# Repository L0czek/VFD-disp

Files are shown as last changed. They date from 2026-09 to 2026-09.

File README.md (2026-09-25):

# IVLM3 driver board

This project was created to drive the old IVLM3-5/7 VFD displays. These tubes are tricolor 5×7 matrices that allow displaying arbitrary shapes, provided you stand far enough for the subpixels to blend. The board consists of several sections and is controlled via an ESP32-C6 module, which uses the HV5812 as the anode and grid driver. These tubes require anode voltages of up to 50V in pulse mode with 3V heating, so the board features a boost and buck converter to achieve these voltages.

**Assembled board.**  
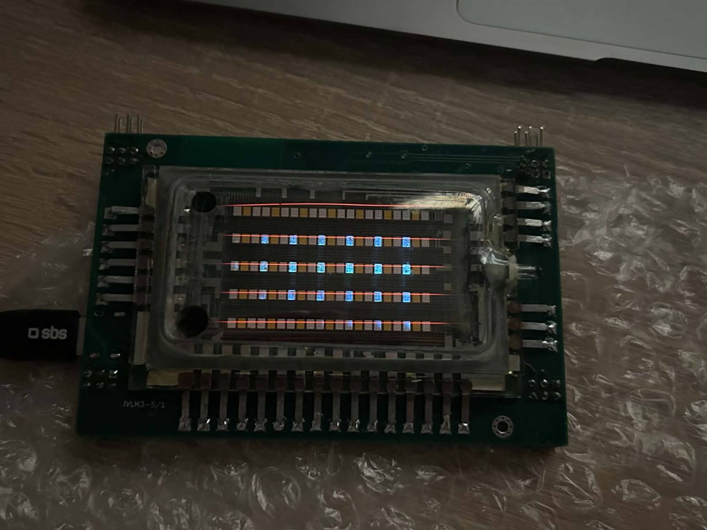
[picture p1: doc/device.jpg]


**All pixels lit at 10V anode.**  
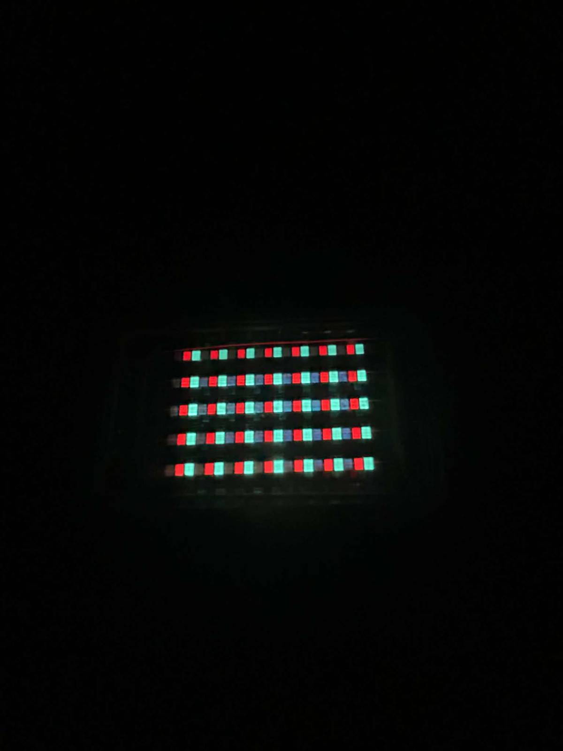
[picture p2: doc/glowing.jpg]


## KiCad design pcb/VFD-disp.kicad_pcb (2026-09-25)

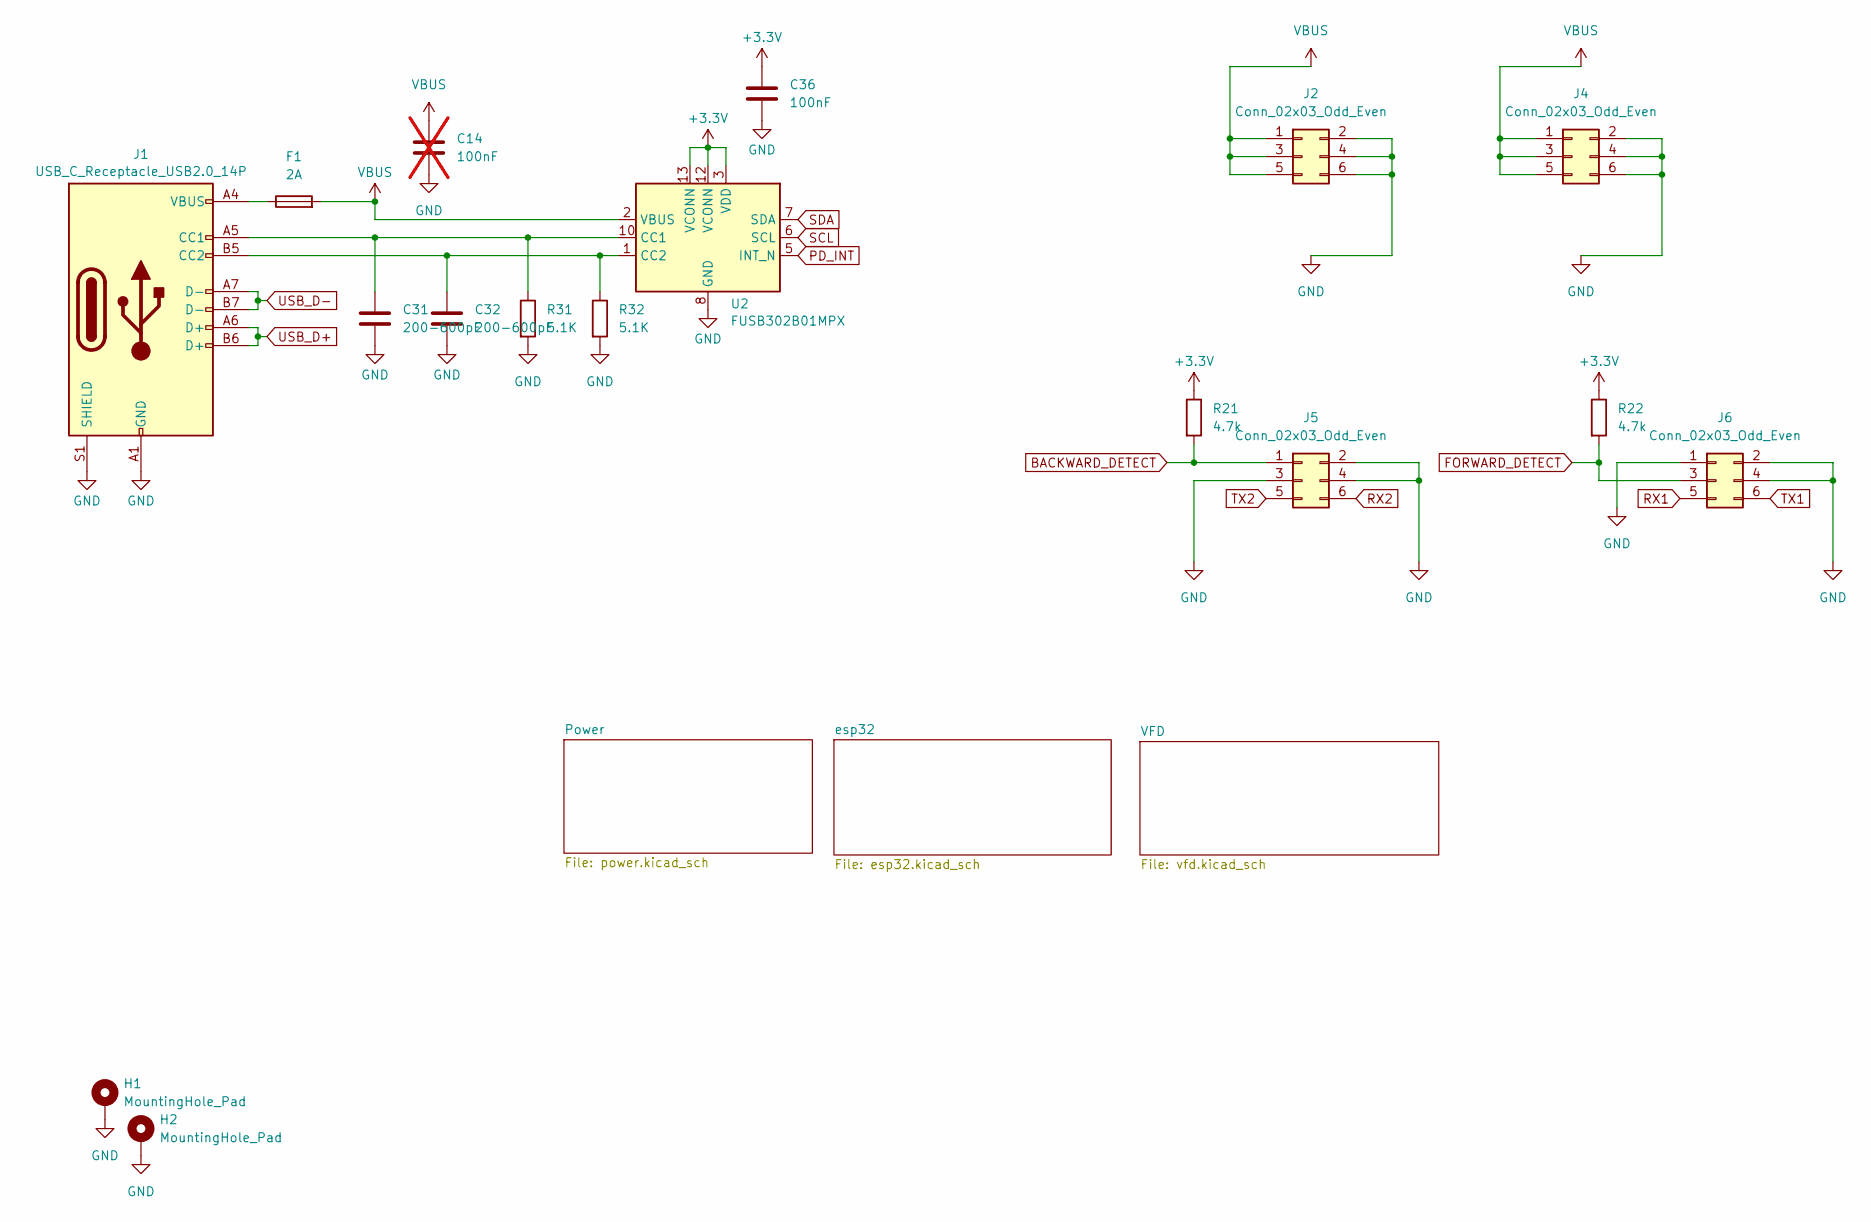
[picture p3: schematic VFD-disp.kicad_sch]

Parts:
C14: 100nF; C_2220_5750Metric; not fitted
C31, C32: 200-600pF; C_0805_2012Metric
C36: 100nF; C_0805_2012Metric; LCSC C7419429
F1: 2A; Fuse_0805_2012Metric
H1, H2: MountingHole_Pad; MountingHole_2.2mm_M2_Pad_Via
J1: USB_C_Receptacle_USB2.0_14P; USB_C_Receptacle_G-Switch_GT-USB-7010ASV
J2, J5: Conn_02x03_Odd_Even; PinSocket_2x03_P2.54mm_Horizontal
J4, J6: Conn_02x03_Odd_Even; PinHeader_2x03_P2.54mm_Horizontal
R21, R22: 4.7k; R_0805_2012Metric; LCSC C7468408
R31, R32: 5.1K; R_0805_2012Metric
U2: FUSB302B01MPX; WQFN-14-1EP_2.5x2.5mm_P0.5mm_EP1.45x1.45mm

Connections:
+3.3V: C36.1, R21.1, R22.1, U2.3 (VDD), U2.4 (VDD), U2.12 (VCONN), U2.13 (VCONN); also elsewhere on the board
BACKWARD_DETECT: J5.1, R21.2; also elsewhere on the board
FORWARD_DETECT: J6.3, R22.2; also elsewhere on the board
GND: C14.2, C31.2, C32.2, C36.2, H1.1 (1_1), H2.1 (1_1), J1.A1 (GND), J1.A12 (GND), J1.B1 (GND), J1.B12 (GND), J1.S1 (SHIELD), J2.2, J2.4, J2.6, J4.2, J4.4, J4.6, J5.2, J5.3, J5.4, J6.1, J6.2, J6.4, R31.2, R32.2, U2.8 (GND), U2.9 (GND), U2.15 (GND); also elsewhere on the board
unnamed: F1.1, J1.A4 (VBUS), J1.A9 (VBUS), J1.B4 (VBUS), J1.B9 (VBUS)
unnamed: C31.1, J1.A5 (CC1), R31.1, U2.10 (CC1), U2.11 (CC1)
unnamed: C32.1, J1.B5 (CC2), R32.1, U2.1 (CC2), U2.14 (CC2)
PD_INT: U2.5 (INT_N); also elsewhere on the board
RX1: J6.5; also elsewhere on the board
RX2: J5.6; also elsewhere on the board
SCL: U2.6 (SCL); also elsewhere on the board
SDA: U2.7 (SDA); also elsewhere on the board
TX1: J6.6; also elsewhere on the board
TX2: J5.5; also elsewhere on the board
USB_D+: J1.A6 (D+), J1.B6 (D+); also elsewhere on the board
USB_D-: J1.A7 (D-), J1.B7 (D-); also elsewhere on the board
VBUS: C14.1, F1.2, J2.1, J2.3, J2.5, J4.1, J4.3, J4.5, U2.2 (VBUS); also elsewhere on the board

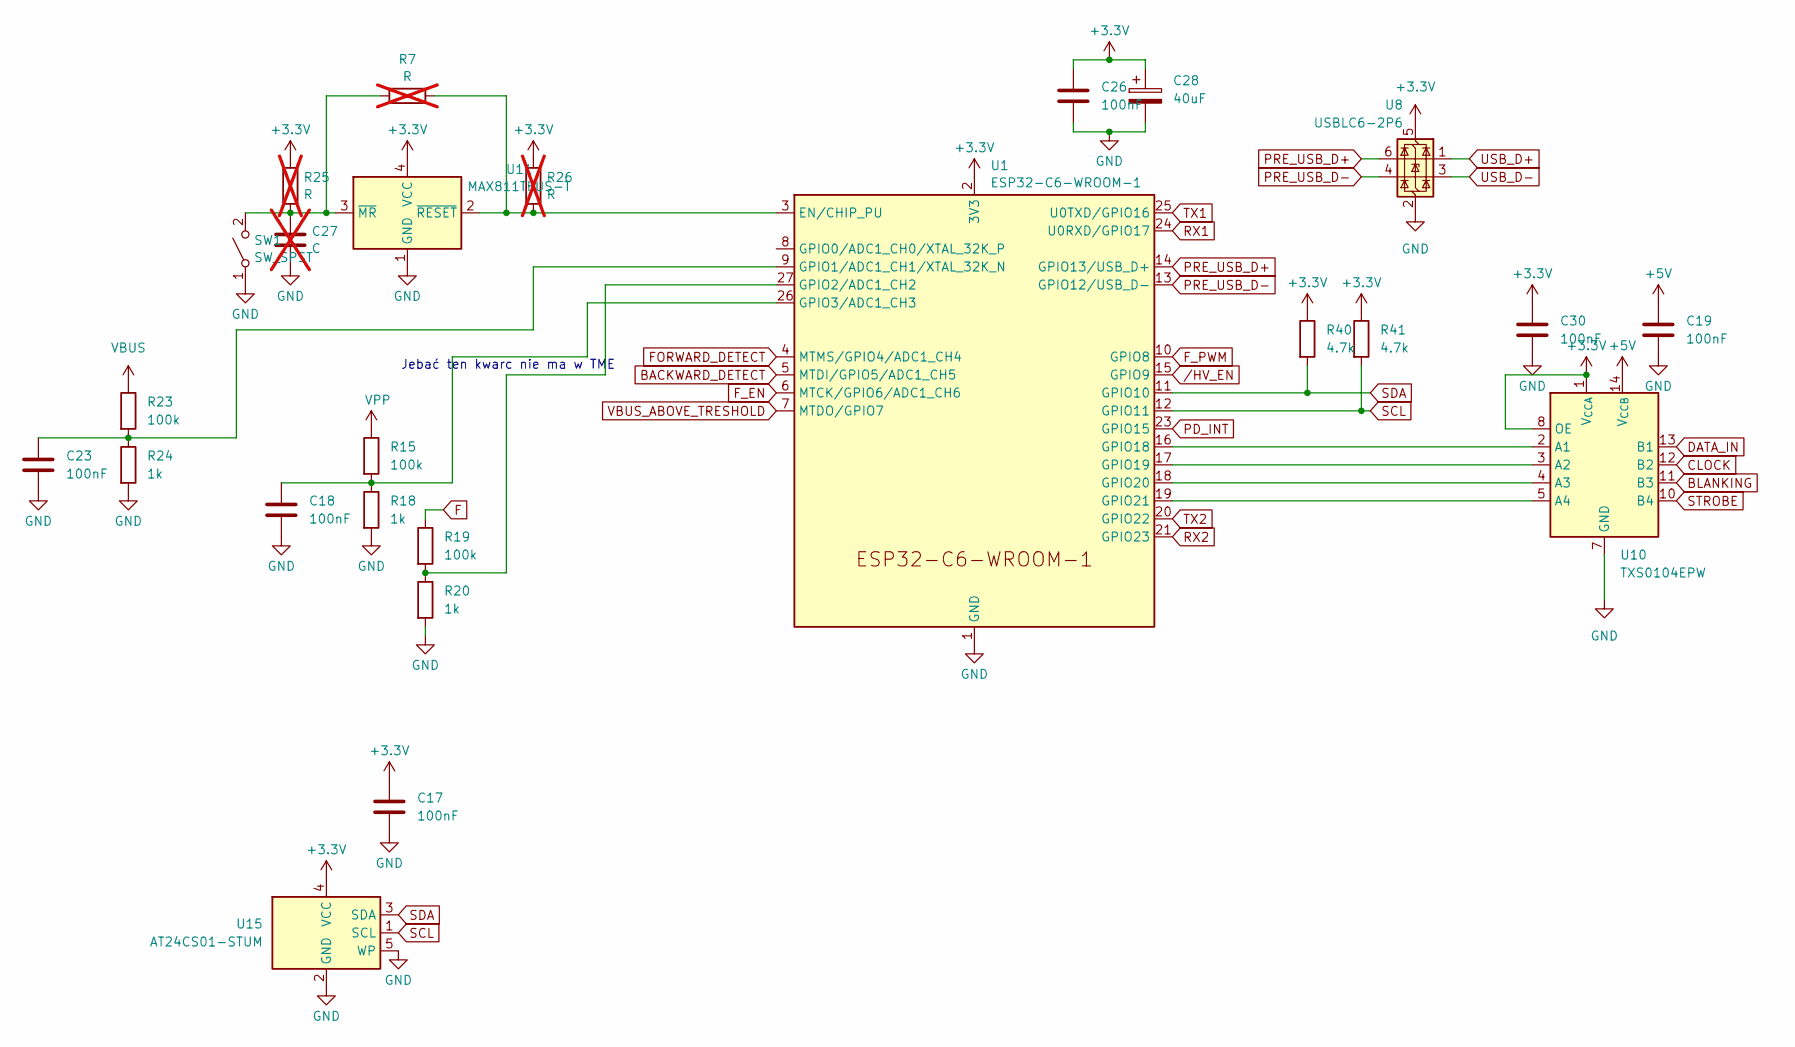
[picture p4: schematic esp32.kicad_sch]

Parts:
C17, C18, C19, C23, C26, C30: 100nF; C_0805_2012Metric; LCSC C7419429
C27: C; C_0805_2012Metric; not fitted
C28: 40uF; CP_EIA-7343-31_Kemet-D
R7, R25, R26: R; R_0805_2012Metric; not fitted
R15, R19, R23: 100k; R_0805_2012Metric; LCSC C7319379
R18, R20, R24: 1k; R_0805_2012Metric; LCSC C6654733
R40, R41: 4.7k; R_0805_2012Metric; LCSC C7468408
SW1: SW_SPST; SW_SPST_B3S-1000
U1: ESP32-C6-WROOM-1
U8: USBLC6-2P6; SOT-666
U10: TXS0104EPW; TSSOP-14_4.4x5mm_P0.65mm
U11: MAX811TEUS-T; SOT-143
U15: AT24CS01-STUM; SOT-23-5

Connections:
+3.3V: C17.1, C26.1, C28.1, C30.1, R25.1, R26.1, R40.1, R41.1, U1.2 (3V3), U8.5 (VBUS), U10.1 (V_{CCA}), U10.8 (OE), U11.4 (VCC), U15.4 (VCC); also elsewhere on the board
+5V: C19.1, U10.14 (V_{CCB}); also elsewhere on the board
BACKWARD_DETECT: U1.5 (MTDI/GPIO5/ADC1_CH5); also elsewhere on the board
BLANKING: U10.11 (B3); also elsewhere on the board
CLOCK: U10.12 (B2); also elsewhere on the board
DATA_IN: U10.13 (B1); also elsewhere on the board
F: R19.1; also elsewhere on the board
FORWARD_DETECT: U1.4 (MTMS/GPIO4/ADC1_CH4); also elsewhere on the board
F_EN: U1.6 (MTCK/GPIO6/ADC1_CH6); also elsewhere on the board
F_PWM: U1.10 (GPIO8); also elsewhere on the board
GND: C17.2, C18.2, C19.2, C23.2, C26.2, C27.2, C28.2, C30.2, R18.2, R20.2, R24.2, SW1.1 (A), U1.1 (GND), U1.28 (GND), U1.29 (GND), U8.2 (GND), U10.7 (GND), U11.1 (GND), U15.2 (GND), U15.5 (WP); also elsewhere on the board
unnamed: C27.1, R7.1, R25.2, SW1.2 (B), U11.3 (~MR)
unnamed: R7.2, R26.2, U1.3 (EN/CHIP_PU), U11.2 (~RESET)
unnamed: C23.1, R23.2, R24.1, U1.9 (GPIO1/ADC1_CH1/XTAL_32K_N)
unnamed: R19.2, R20.1, U1.27 (GPIO2/ADC1_CH2)
unnamed: C18.1, R15.2, R18.1, U1.26 (GPIO3/ADC1_CH3)
unnamed: U1.16 (GPIO18), U10.2 (A1)
unnamed: U1.17 (GPIO19), U10.3 (A2)
unnamed: U1.18 (GPIO20), U10.4 (A3)
unnamed: U1.19 (GPIO21), U10.5 (A4)
PD_INT: U1.23 (GPIO15); also elsewhere on the board
PRE_USB_D+: U1.14 (GPIO13/USB_D+), U8.6 (I/O1)
PRE_USB_D-: U1.13 (GPIO12/USB_D-), U8.4 (I/O2)
RX1: U1.24 (U0RXD/GPIO17); also elsewhere on the board
RX2: U1.21 (GPIO23); also elsewhere on the board
SCL: R41.2, U1.12 (GPIO11), U15.1 (SCL); also elsewhere on the board
SDA: R40.2, U1.11 (GPIO10), U15.3 (SDA); also elsewhere on the board
STROBE: U10.10 (B4); also elsewhere on the board
TX1: U1.25 (U0TXD/GPIO16); also elsewhere on the board
TX2: U1.20 (GPIO22); also elsewhere on the board
USB_D+: U8.1 (I/O1); also elsewhere on the board
USB_D-: U8.3 (I/O2); also elsewhere on the board
VBUS: R23.1; also elsewhere on the board
VBUS_ABOVE_TRESHOLD: U1.7 (MTDO/GPIO7)
VPP: R15.1; also elsewhere on the board
/HV_EN: U1.15 (GPIO9)

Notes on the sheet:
Jebać ten kwarc nie ma w TME

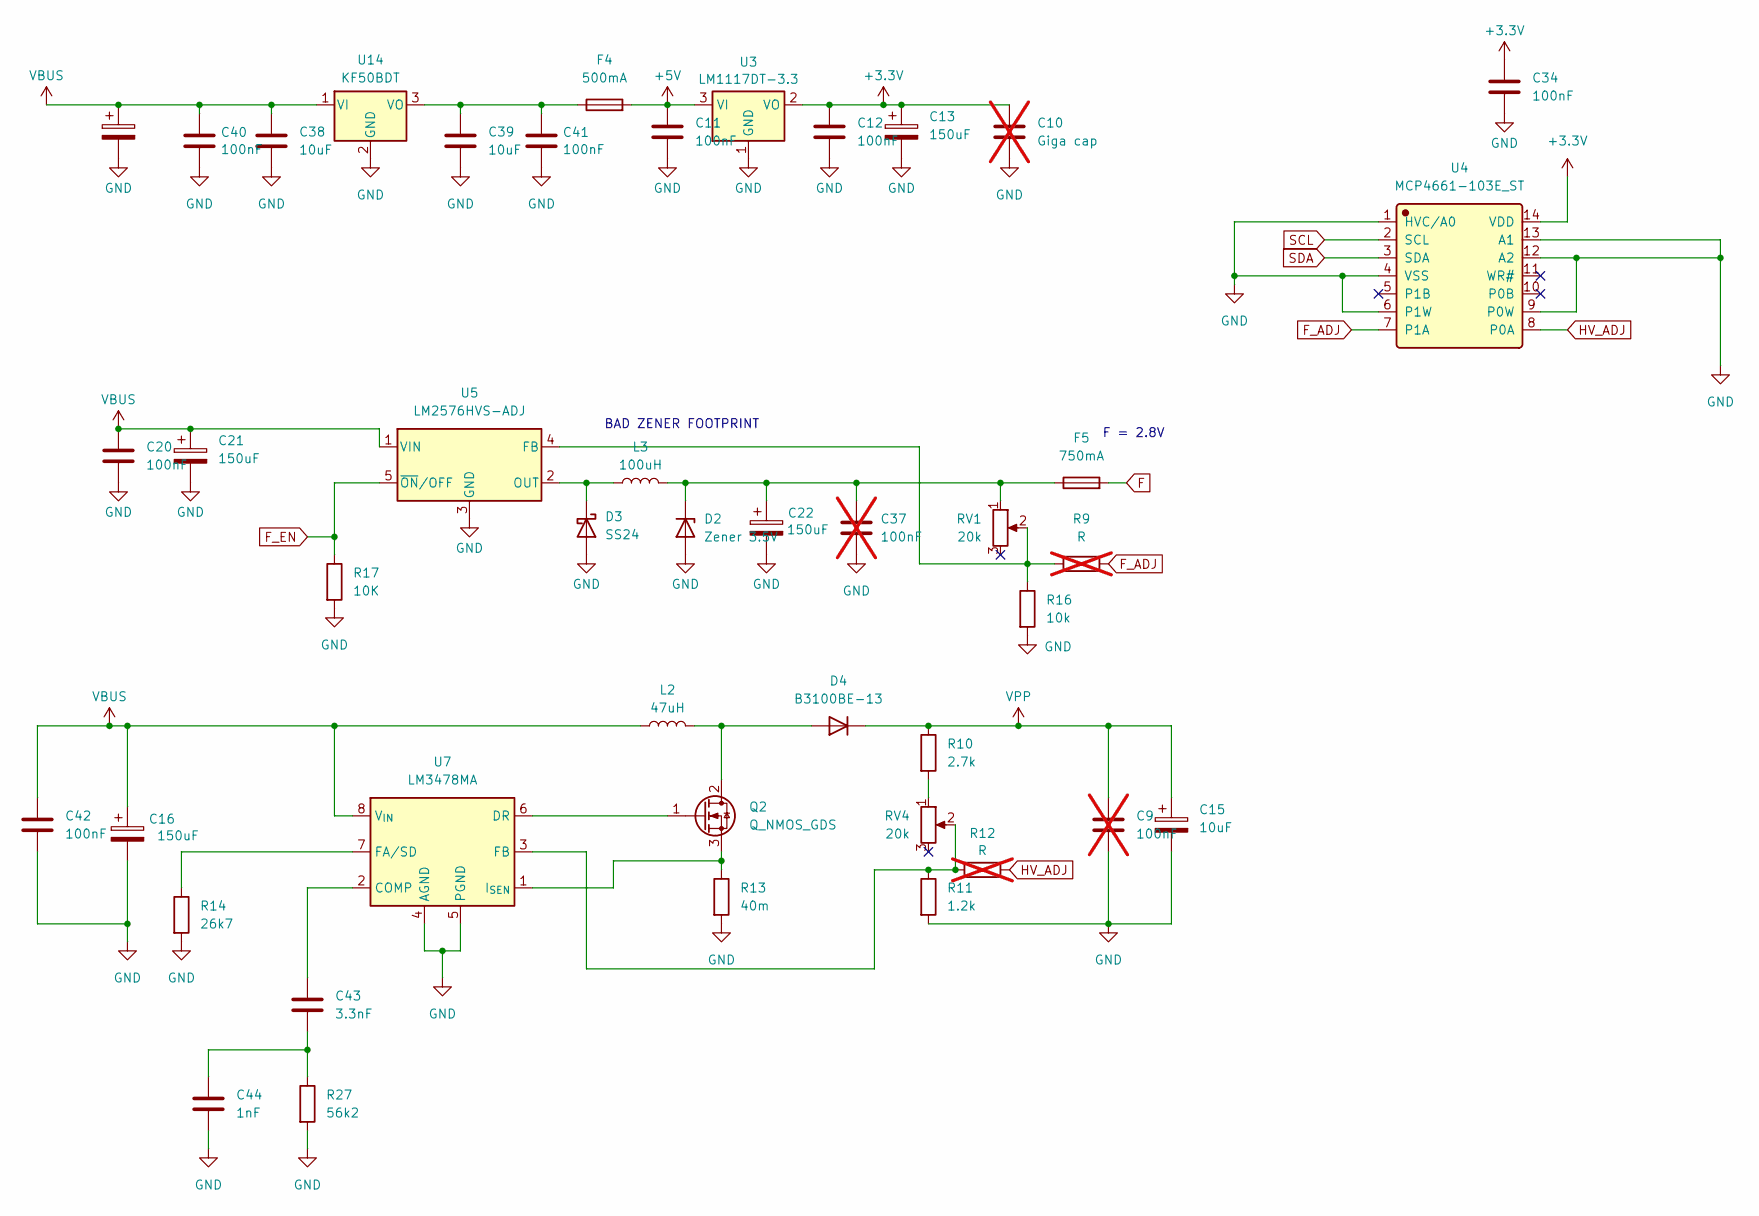
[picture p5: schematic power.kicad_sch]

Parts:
C9: 100nF; C_2220_5750Metric; LCSC C7419429; not fitted
C10: Giga cap; C_2220_5750Metric; not fitted
C11, C12, C20, C34, C40, C41, C42: 100nF; C_0805_2012Metric; LCSC C7419429
C13, C16, C21, C22, C24: 150uF; CP_Elec_5x4.5
C15: 10uF; CP_Elec_5x4.5
C37: 100nF; C_2220_5750Metric; not fitted
C38, C39: 10uF; C_1206_3216Metric
C43: 3.3nF; C_0805_2012Metric
C44: 1nF; C_0805_2012Metric
D2: Zener 3.5V; D_SMB
D3: SS24; D_SMB; LCSC C7420362
D4: B3100BE-13; D_SMB
F4: 500mA; Fuse_0805_2012Metric
F5: 750mA; Fuse_0805_2012Metric
L2: 47uH; C_2220_5750Metric
L3: 100uH; L_Bourns_SRP1038C_10.0x10.0mm
Q2: Q_NMOS_GDS; TO-252-2
R9, R12: R; R_0805_2012Metric; not fitted
R10: 2.7k; R_0805_2012Metric
R11: 1.2k; R_0805_2012Metric
R13: 40m; R_0805_2012Metric
R14: 26k7; R_0805_2012Metric; LCSC C7319379
R16: 10k; R_0805_2012Metric; LCSC C7319379
R17: 10K; R_0805_2012Metric; LCSC C7319379
R27: 56k2; R_0805_2012Metric; LCSC C6654733
RV1, RV4: 20k; Potentiometer_Bourns_3269W_Vertical
U3: LM1117DT-3.3; TO-252-3_TabPin2
U4: MCP4661-103E_ST; TSSOP-14_4.4x5mm_P0.65mm; Manufacturer Part MCP4661-103E/ST
U5: LM2576HVS-ADJ; TO-263-5_TabPin3; LCSC C7419972
U7: LM3478MA; SOIC-8_3.9x4.9mm_P1.27mm
U14: KF50BDT; TO-252-2

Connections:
+3.3V: C10.1, C12.1, C13.1, C34.1, U3.2 (VO), U4.14 (VDD); also elsewhere on the board
+5V: C11.1, F4.2, U3.3 (VI); also elsewhere on the board
F: F5.2; also elsewhere on the board
F_ADJ: R9.2, U4.7 (P1A)
F_EN: R17.1, U5.5 (~ON/OFF); also elsewhere on the board
GND: C9.2, C10.2, C11.2, C12.2, C13.2, C15.2, C16.2, C20.2, C21.2, C22.2, C24.2, C34.2, C37.2, C38.2, C39.2, C40.2, C41.2, C42.2, C44.2, D2.2 (A), D3.2 (A), R11.2, R13.2, R14.2, R16.2, R17.2, R27.2, U3.1 (GND), U4.1 (HVC/A0), U4.4 (VSS), U4.6 (P1W), U4.9 (P0W), U4.12 (A2), U4.13 (A1), U5.3 (GND), U7.4 (AGND), U7.5 (PGND), U14.2 (GND); also elsewhere on the board
HV_ADJ: R12.2, U4.8 (P0A)
unnamed: C43.2, C44.1, R27.1
unnamed: C22.1, C37.1, D2.1 (K), F5.1, L3.2, RV1.1
unnamed: D3.1 (K), L3.1, U5.2 (OUT)
unnamed: D4.2 (A), L2.2, Q2.2 (D)
unnamed: Q2.1 (G), U7.6 (DR)
unnamed: Q2.3 (S), R13.1, U7.1 (I_{SEN})
unnamed: R10.2, RV4.1
unnamed: R9.1, R16.1, RV1.2, U5.4 (FB)
unnamed: C43.1, U7.2 (COMP)
unnamed: R14.1, U7.7 (FA/SD)
unnamed: R11.1, R12.1, RV4.2, U7.3 (FB)
unnamed: C39.1, C41.1, F4.1, U14.3 (VO)
SCL: U4.2 (SCL); also elsewhere on the board
SDA: U4.3 (SDA); also elsewhere on the board
VBUS: C16.1, C20.1, C21.1, C24.1, C38.1, C40.1, C42.1, L2.1, U5.1 (VIN), U7.8 (V_{IN}), U14.1 (VI); also elsewhere on the board
VPP: C9.1, C15.1, D4.1 (K), R10.1; also elsewhere on the board

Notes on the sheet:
F = 2.8V
BAD ZENER FOOTPRINT

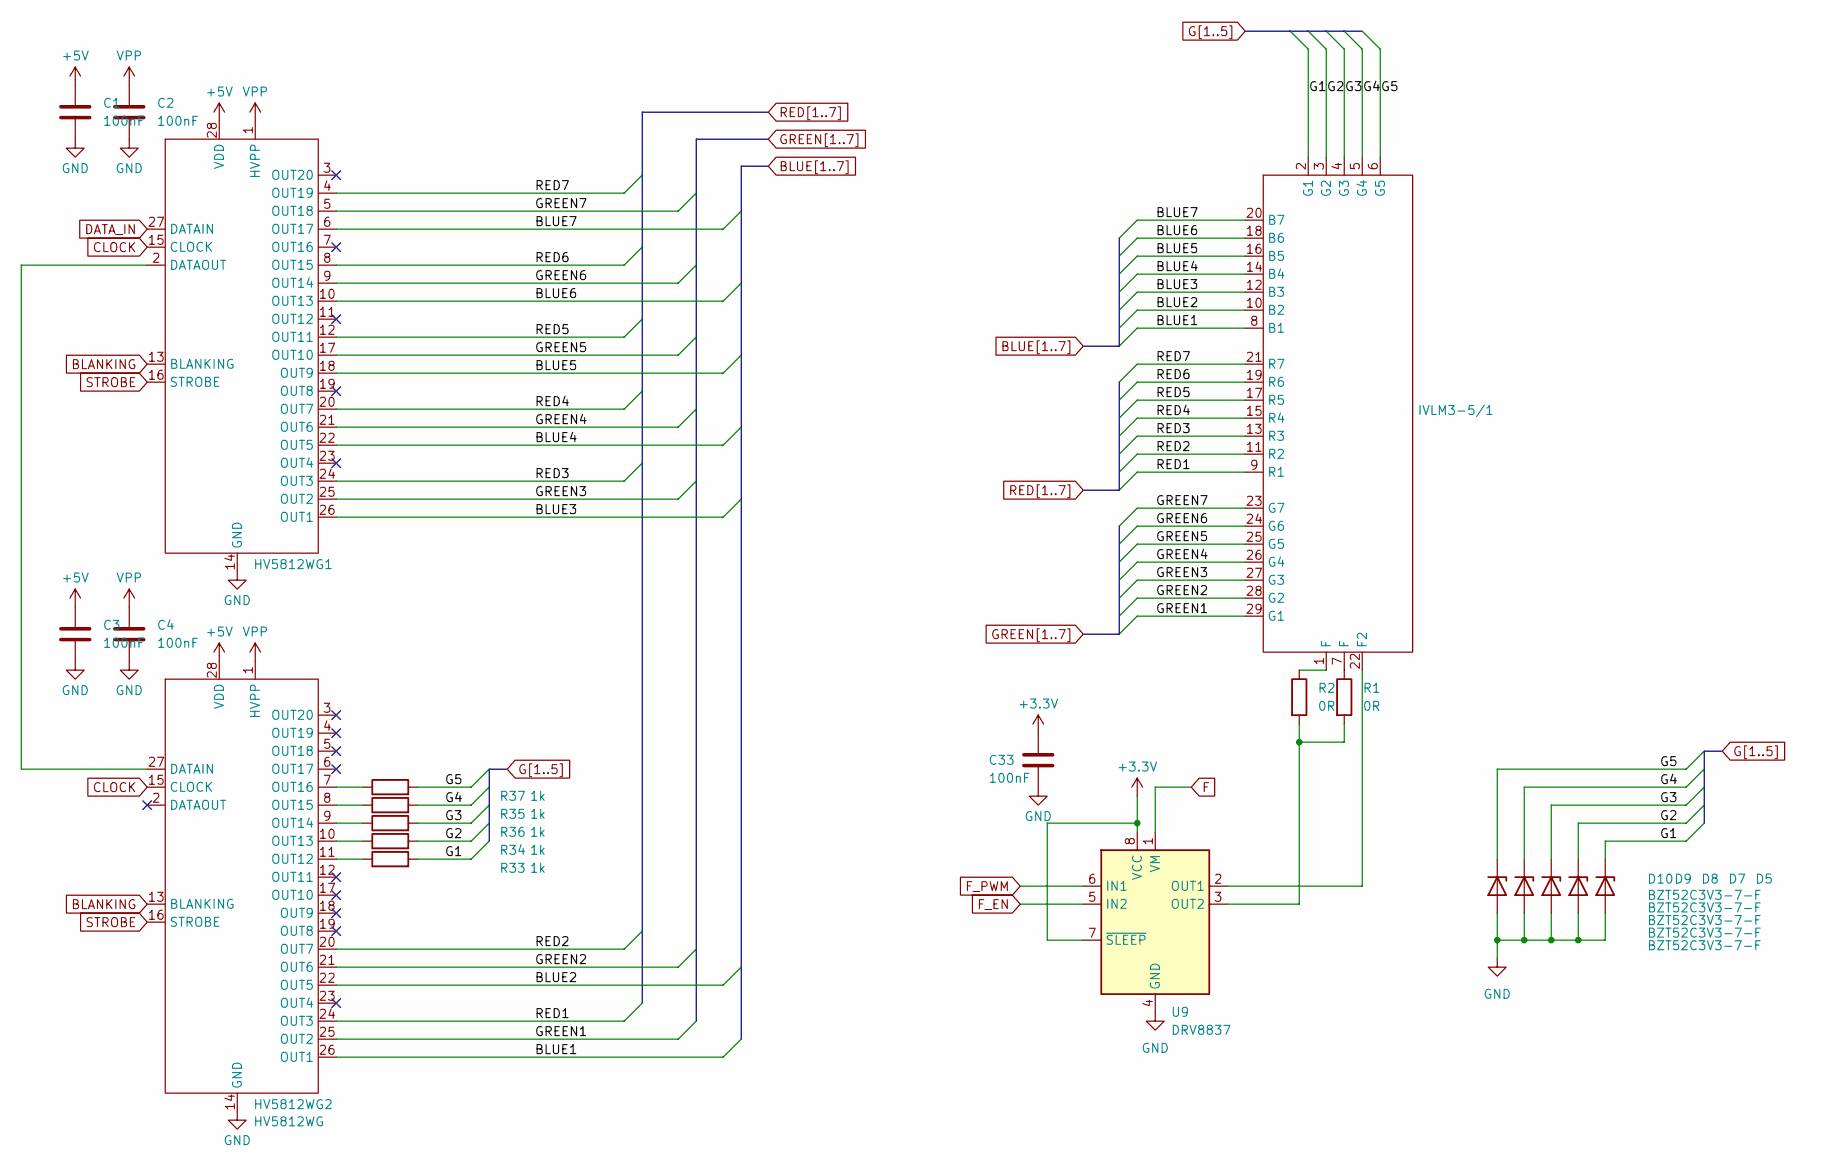
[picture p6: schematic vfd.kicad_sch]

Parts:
C1, C2, C3, C4, C33: 100nF; C_0805_2012Metric; LCSC C7419429
D5: BZT52C3V3-7-F; D_SOD-123
D7, D8, D9, D10: BZT52C3V3-7-F; D_SOD-123; LCSC C7420362
HV5812WG1, HV5812WG2: HV5812WG; SOIC-28W_7.5x17.9mm_P1.27mm
IVLM3-5/1: IVLM3-5_7
R1, R2: 0R; R_0805_2012Metric; LCSC C7610430
R33, R34, R35, R36, R37: 1k; R_0805_2012Metric; LCSC C6654733
U9: DRV8837; WSON-8-1EP_2x2mm_P0.5mm_EP0.9x1.6mm

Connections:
+3.3V: C33.1, U9.7 (~SLEEP), U9.8 (VCC); also elsewhere on the board
+5V: C1.1, C3.1, HV5812WG1.28 (VDD), HV5812WG2.28 (VDD); also elsewhere on the board
BLANKING: HV5812WG1.13 (BLANKING), HV5812WG2.13 (BLANKING); also elsewhere on the board
BLUE1: HV5812WG2.26 (OUT1), IVLM3-5/1.8 (B1)
BLUE2: HV5812WG2.22 (OUT5), IVLM3-5/1.10 (B2)
BLUE3: HV5812WG1.26 (OUT1), IVLM3-5/1.12 (B3)
BLUE4: HV5812WG1.22 (OUT5), IVLM3-5/1.14 (B4)
BLUE5: HV5812WG1.18 (OUT9), IVLM3-5/1.16 (B5)
BLUE6: HV5812WG1.10 (OUT13), IVLM3-5/1.18 (B6)
BLUE7: HV5812WG1.6 (OUT17), IVLM3-5/1.20 (B7)
CLOCK: HV5812WG1.15 (CLOCK), HV5812WG2.15 (CLOCK); also elsewhere on the board
DATA_IN: HV5812WG1.27 (DATAIN); also elsewhere on the board
F: U9.1 (VM); also elsewhere on the board
F_EN: U9.5 (IN2); also elsewhere on the board
F_PWM: U9.6 (IN1); also elsewhere on the board
G1: D5.1 (K), IVLM3-5/1.2 (G1), R33.2
G2: D7.1 (K), IVLM3-5/1.3 (G2), R34.2
G3: D8.1 (K), IVLM3-5/1.4 (G3), R36.2
G4: D9.1 (K), IVLM3-5/1.5 (G4), R35.2
G5: D10.1 (K), IVLM3-5/1.6 (G5), R37.2
GND: C1.2, C2.2, C3.2, C4.2, C33.2, D5.2 (A), D7.2 (A), D8.2 (A), D9.2 (A), D10.2 (A), HV5812WG1.14 (GND), HV5812WG2.14 (GND), U9.4 (GND), U9.9 (GND); also elsewhere on the board
GREEN1: HV5812WG2.25 (OUT2), IVLM3-5/1.29 (G1)
GREEN2: HV5812WG2.21 (OUT6), IVLM3-5/1.28 (G2)
GREEN3: HV5812WG1.25 (OUT2), IVLM3-5/1.27 (G3)
GREEN4: HV5812WG1.21 (OUT6), IVLM3-5/1.26 (G4)
GREEN5: HV5812WG1.17 (OUT10), IVLM3-5/1.25 (G5)
GREEN6: HV5812WG1.9 (OUT14), IVLM3-5/1.24 (G6)
GREEN7: HV5812WG1.5 (OUT18), IVLM3-5/1.23 (G7)
unnamed: HV5812WG1.2 (DATAOUT), HV5812WG2.27 (DATAIN)
unnamed: HV5812WG2.11 (OUT12), R33.1
unnamed: HV5812WG2.10 (OUT13), R34.1
unnamed: HV5812WG2.9 (OUT14), R36.1
unnamed: HV5812WG2.8 (OUT15), R35.1
unnamed: HV5812WG2.7 (OUT16), R37.1
unnamed: IVLM3-5/1.22 (F2), U9.2 (OUT1)
unnamed: IVLM3-5/1.1 (F), R2.1
unnamed: IVLM3-5/1.7 (F), R1.1
unnamed: R1.2, R2.2, U9.3 (OUT2)
RED1: HV5812WG2.24 (OUT3), IVLM3-5/1.9 (R1)
RED2: HV5812WG2.20 (OUT7), IVLM3-5/1.11 (R2)
RED3: HV5812WG1.24 (OUT3), IVLM3-5/1.13 (R3)
RED4: HV5812WG1.20 (OUT7), IVLM3-5/1.15 (R4)
RED5: HV5812WG1.12 (OUT11), IVLM3-5/1.17 (R5)
RED6: HV5812WG1.8 (OUT15), IVLM3-5/1.19 (R6)
RED7: HV5812WG1.4 (OUT19), IVLM3-5/1.21 (R7)
STROBE: HV5812WG1.16 (STROBE), HV5812WG2.16 (STROBE); also elsewhere on the board
VPP: C2.1, C4.1, HV5812WG1.1 (HVPP), HV5812WG2.1 (HVPP); also elsewhere on the board

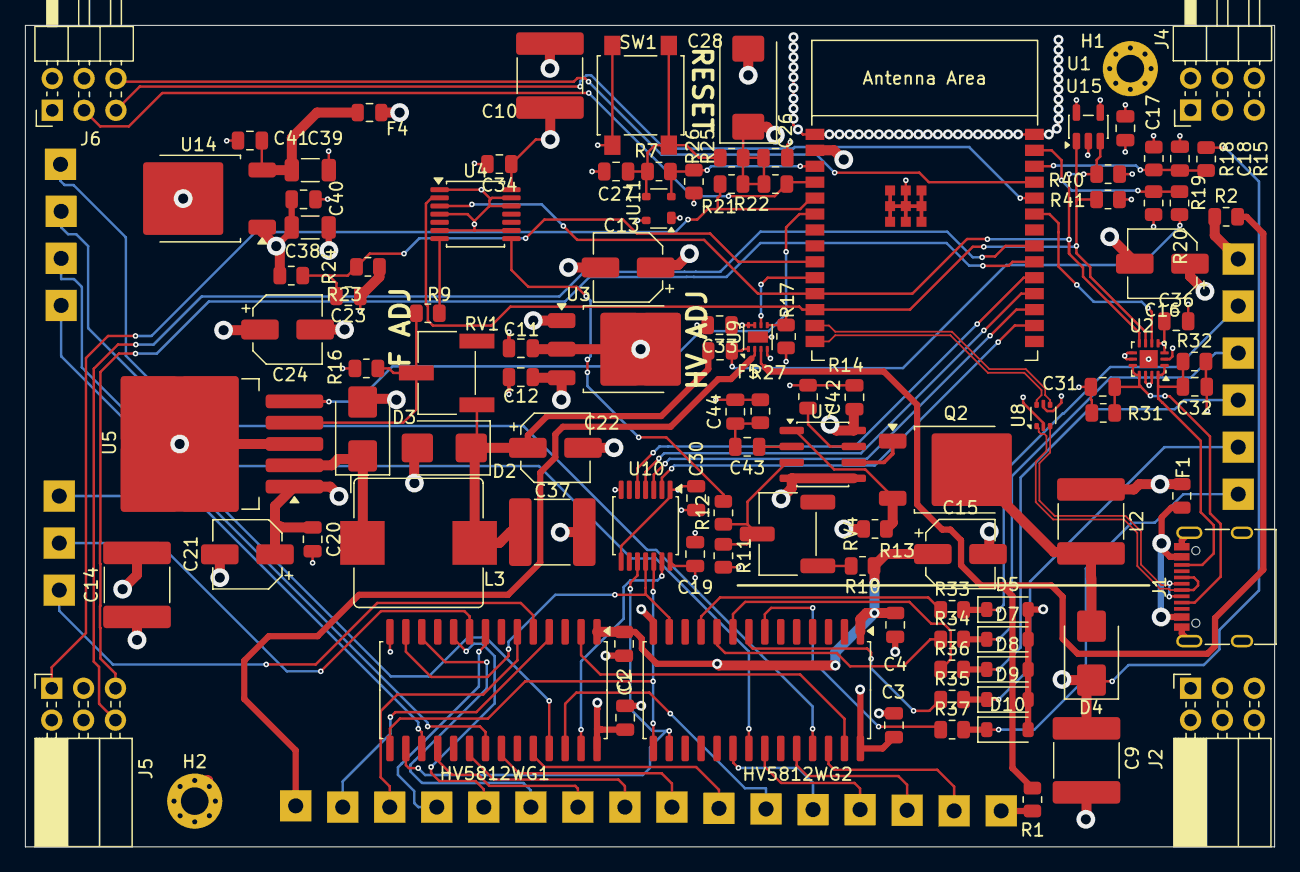
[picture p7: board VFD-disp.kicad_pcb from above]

Board: 4 copper layers, 99.6 x 65.5 mm, 107 parts (1 on the bottom side), 87 nets.

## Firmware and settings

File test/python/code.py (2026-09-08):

from machine import *
import time
adc_f = ADC(2)
adc_hv = ADC(3)

disable_f = Pin(6, Pin.OUT, value=1)
disable_hv = Pin(9, Pin.OUT, value=1)
mosfet = Pin(8, Pin.OUT, value = 0)

spi = SPI(
    1,
    baudrate=100_000,
    polarity=0,
    phase=0,
    sck=Pin(19),
    mosi=Pin(18),
)

# also known as "strobe"
latch = Pin(21, Pin.OUT, value=0)
blanking = Pin(20, Pin.OUT, value=0)

def write_shift_register(value):
    if len(value) != 5:
        print("gowno dales")
    spi.write(bytes(value))
    latch.on()
    time.sleep_ms(1)
    latch.off()
    print("Wrote", value)

write_shift_register([0xAA]*5)

def print_voltages():
    print("HV: ", adc_hv.read_uv()*101.0/1000000)
    print("F: ", adc_f.read_uv()*101.0/1000000)


print_voltages()
time.sleep(1)
disable_f.value(0)
time.sleep(1)
print_voltages()
mosfet.on()
print("f_pwm on")
time.sleep(3)
disable_hv.value(0)
print("hv on")
time.sleep(5)


for i in range(100000):
    time.sleep(1)
    write_shift_register([i%256]*5)
    print_voltages()

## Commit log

2026-03-13 Make schematic ready for routing
    [VFD-disp.kicad_pcb, VFD-disp.kicad_sch]
2026-03-14 WIP płytka
    [VFD-disp.kicad_pcb, VFD-disp.kicad_sch]
2026-03-16 WIP all components placed
    [VFD-disp.kicad_pcb, VFD-disp.kicad_sch]
2026-03-16 WIP connecting...
    [VFD-disp.kicad_pcb, VFD-disp.kicad_sch]
2026-03-16 All Connected!
    [VFD-disp.kicad_pcb]
2026-03-17 We need to golf!
    [VFD-disp.kicad_pcb, VFD-disp.kicad_sch]
2026-03-18 Reroute pcb
    [VFD-disp.kicad_pcb, VFD-disp.kicad_sch]
2026-03-18 Add chonky cermaics caps to be safe...
    [VFD-disp.kicad_pcb, VFD-disp.kicad_sch]
2026-03-26 Finish pcb
    [VFD-disp.kicad_pcb, VFD-disp.kicad_sch]
2026-03-29 Add mounting holes and some rework
    [VFD-disp.kicad_pcb, VFD-disp.kicad_sch]
2026-04-06 Fix DRC errors
    [VFD-disp.kicad_pcb]
2026-04-06 Add CC lines pull down
    [VFD-disp.kicad_pcb, VFD-disp.kicad_sch]
2026-04-06 Fix screw connections
    [VFD-disp.kicad_pcb, VFD-disp.kicad_sch]
2026-05-21 Fix docking connectors reroute usb
    [VFD-disp.kicad_pcb]
2026-05-23 Fix silkscreen and plot gerber
    [VFD-disp-B_Cu.gbl, VFD-disp-B_Mask.gbs, VFD-disp-B_Paste.gbp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]
2026-07-05 wip: values
    [VFD-disp.kicad_sch]
2026-07-21 values and TME
    [VFD-disp.kicad_pcb, VFD-disp.kicad_sch]
2026-08-07 some changes
    [VFD-disp.kicad_pcb, VFD-disp.kicad_sch]
2026-08-11 some resistor values
    [VFD-disp.kicad_sch]
2026-09-08 first working code
    [VFD-disp.kicad_pcb, VFD-disp.kicad_sch]
2026-09-09 update PCB with fixed values
    [VFD-disp.kicad_pcb, VFD-disp.kicad_sch]
2026-09-15 Rev 2 of schematic
    [VFD-disp.kicad_pcb, VFD-disp.kicad_sch]
2026-09-24 run autoroute
    [VFD-disp.kicad_pcb, VFD-disp.kicad_sch]
2026-09-24 Finish routing
    [VFD-disp.kicad_pcb]
2026-09-24 Update schematic
    [VFD-disp.kicad_pcb, VFD-disp.kicad_sch]
2026-09-25 Fix USB and heater traces
    [VFD-disp.kicad_pcb, VFD-disp.kicad_sch]
2026-09-25 Split schematic into pages
    [VFD-disp.kicad_sch, esp32.kicad_sch, power.kicad_sch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]
2026-09-25 Change directory layout
    [VFD-disp-B_Cu.gbl, VFD-disp-B_Mask.gbs, VFD-disp-B_Paste.gbp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]
